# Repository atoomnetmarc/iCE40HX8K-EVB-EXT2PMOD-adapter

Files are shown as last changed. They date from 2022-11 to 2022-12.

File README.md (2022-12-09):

# iCE40HX8K-EVB-EXT to 4 PMOD port adapter.

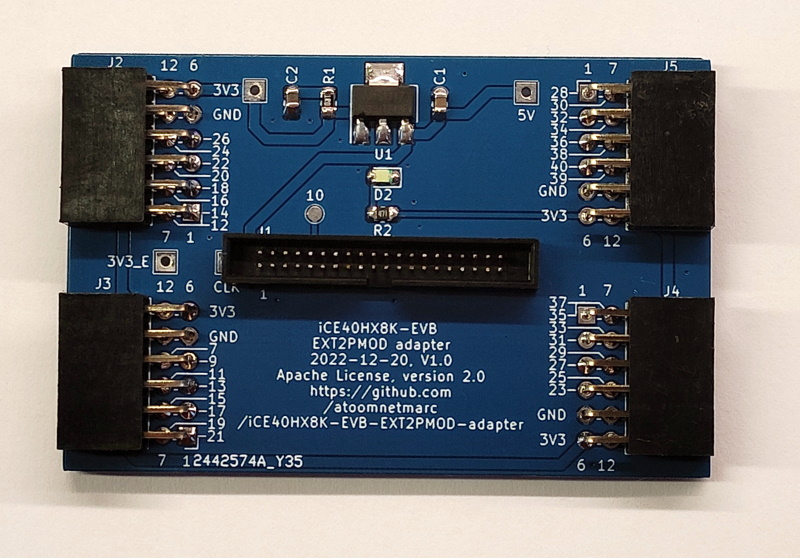
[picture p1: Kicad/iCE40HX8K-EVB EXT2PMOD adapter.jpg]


# Soldering

Solder every SMD component. Measure if 5V gets regulates to 3V3.

Solder every through-hole component. Measure for shorts between any of the signal pins on the tiny 1.27 header J1, correct if needed.

Clean the PCB.

# Pin mapping from PMOD to iCE40HX8K

Header on adapter (J2, J3, J4, J5 column) ➔ pin number on EXT connector (EXT column) ➔ FPGA pin when using EXTx (EXT1, EXT2, EXT3, EXT4 column) connector on FPGA board.

| J2 | EXT | EXT1  | EXT2  | EXT3  | EXT4  |
| -- | -- | -- | -- | -- | -- |
| 1 | 14 | A7 | K12 | D15 | M5 |
| 2 | 18 | D8 | L13 | F14 | M4 |
| 3 | 22 | F7 | L12 | D16 | N3 |
| 4 | 26 | F9 | M13 | E16 | M3 |
| 7 | 12 | C7 | M16 | F11 | R1 |
| 8 | 16 | B8 | L14 | F12 | P2 |
| 9 | 20 | B9 | N16 | G12 | P1 |
| 10 | 24 | C8 | M14 | G13 | L5 |

| J3 | EXT | EXT1  | EXT2  | EXT3  | EXT4  |
| -- | -- | -- | -- | -- | -- |
| 1 | 21 | A16 | E6 | K16 | N12 |
| 2 | 17 | E11 | A5 | J15 | M11 |
| 3 | 13 | B14 | A6 | K13 | E13 |
| 4 | 9 | B15 | C6 | J11 | F13 |
| 7 | 19 | C13 | B5 | K15 | T13 |
| 8 | 15 | C12 | D6 | K14 | D14 |
| 9 | 11 | D13 | D7 | L16 | B16 |
| 10 | 7 | C14 | B6 | M15 | C16 |

| J4 | EXT | EXT1  | EXT2  | EXT3  | EXT4  |
| -- | -- | -- | -- | -- | -- |
| 1 | 35 | B10 | B3 | H16 | L1 |
| 2 | 31 | D11 | C5 | H13 | K3 |
| 3 | 27 | E10 | D5 | J13 | J1 |
| 4 | 23 | A15 | B4 | J14 | M12 |
| 7 | 37 | B11 | D4 | H14 | K4 |
| 8 | 33 | B12 | C4 | H11 | L4 |
| 9 | 29 | C11 | A1 | J16 | K1 |
| 10 | 25 | B13 | A2 | J12 | R16 |

| J5 | EXT | EXT1  | EXT2  | EXT3  | EXT4  |
| -- | -- | -- | -- | -- | -- |
| 1 | 28 | A9 | P16 | G14 | M6 |
| 2 | 32 | E9 | P14 | G11 | L7 |
| 3 | 36 | D10 | R14 | G10 | K5 |
| 4 | 40 | A10 | D3 | H12 | L6 |
| 7 | 30 | D9 | P15 | F15 | N2 |
| 8 | 34 | C9 | R15 | F16 | M2 |
| 9 | 38 | A11 | C3 | G15 | L3 |
| 10 | 39 | C10 | E5 | G16 | M1 |



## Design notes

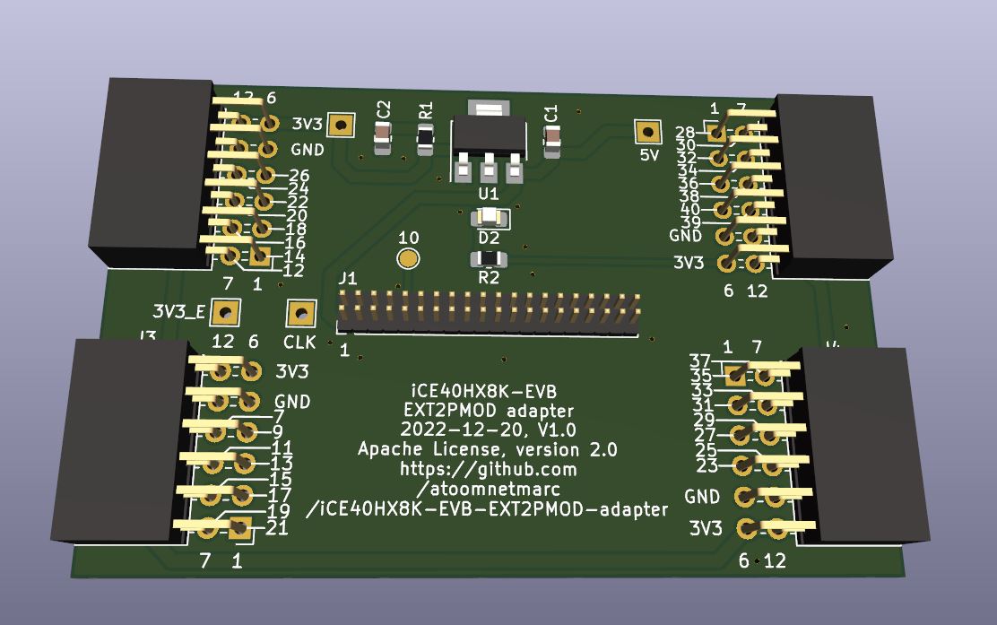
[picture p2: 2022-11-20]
Kicad/iCE40HX8K-EVB EXT2PMOD adapter-render.jpg

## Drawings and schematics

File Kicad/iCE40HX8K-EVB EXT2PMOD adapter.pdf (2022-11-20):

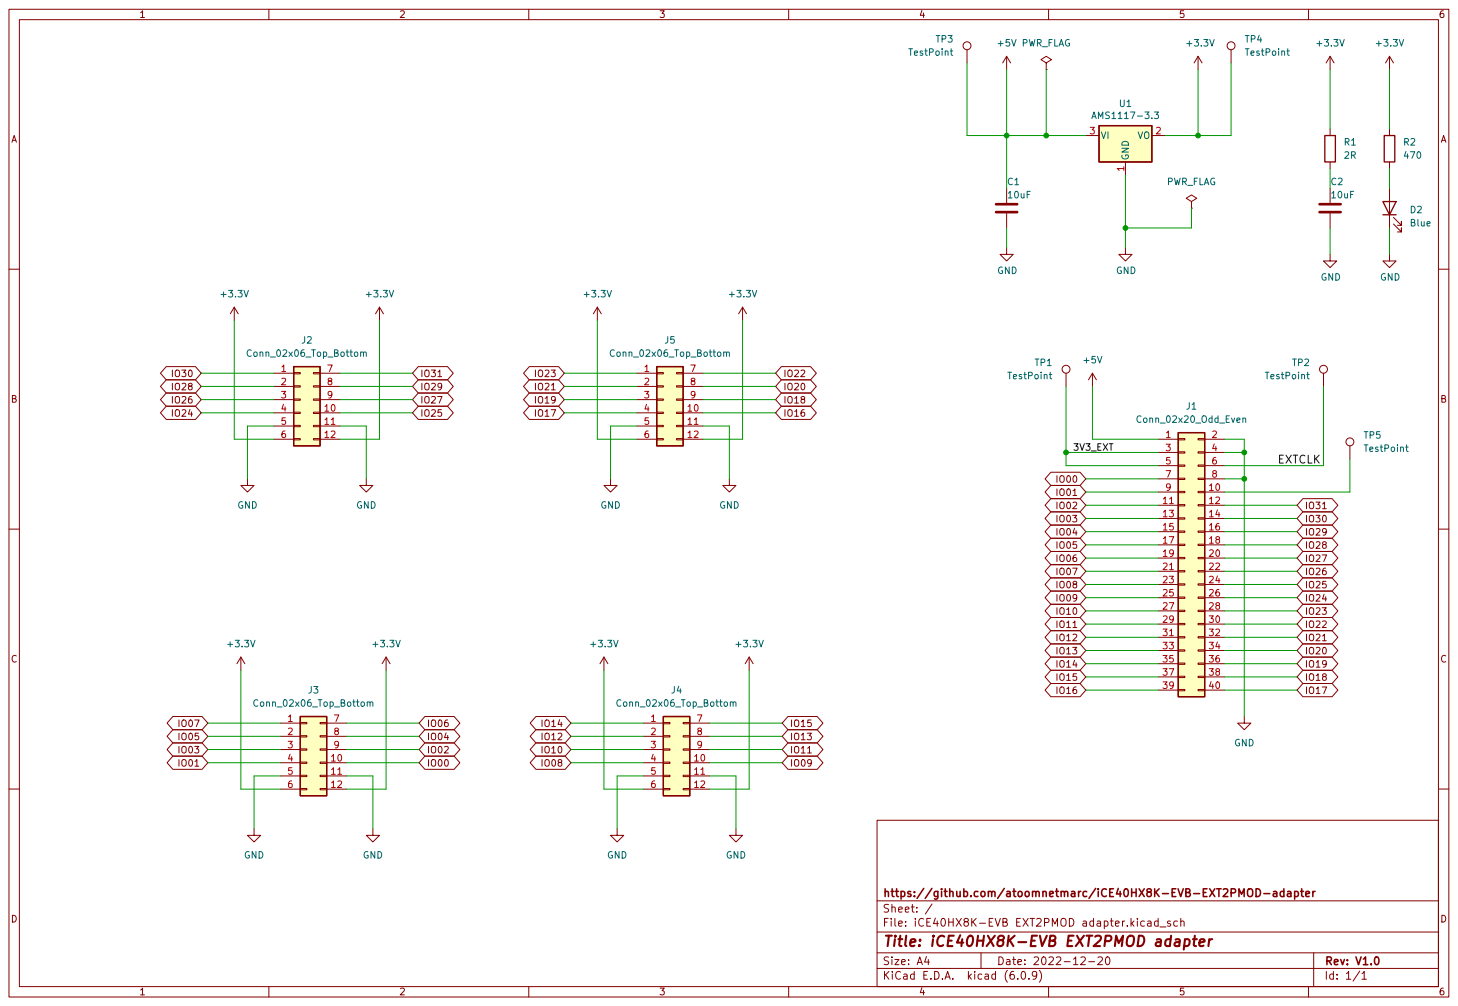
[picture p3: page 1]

File: iCE40HX8K-EVB EXT2PMOD adapter.kicad_sch Sheet: / https://github.com/atoomnetmarc/iCE40HX8K-EVB-EXT2PMOD-adapter

Id: 1/1 Title: iCE40HX8K-EVB EXT2PMOD adapter

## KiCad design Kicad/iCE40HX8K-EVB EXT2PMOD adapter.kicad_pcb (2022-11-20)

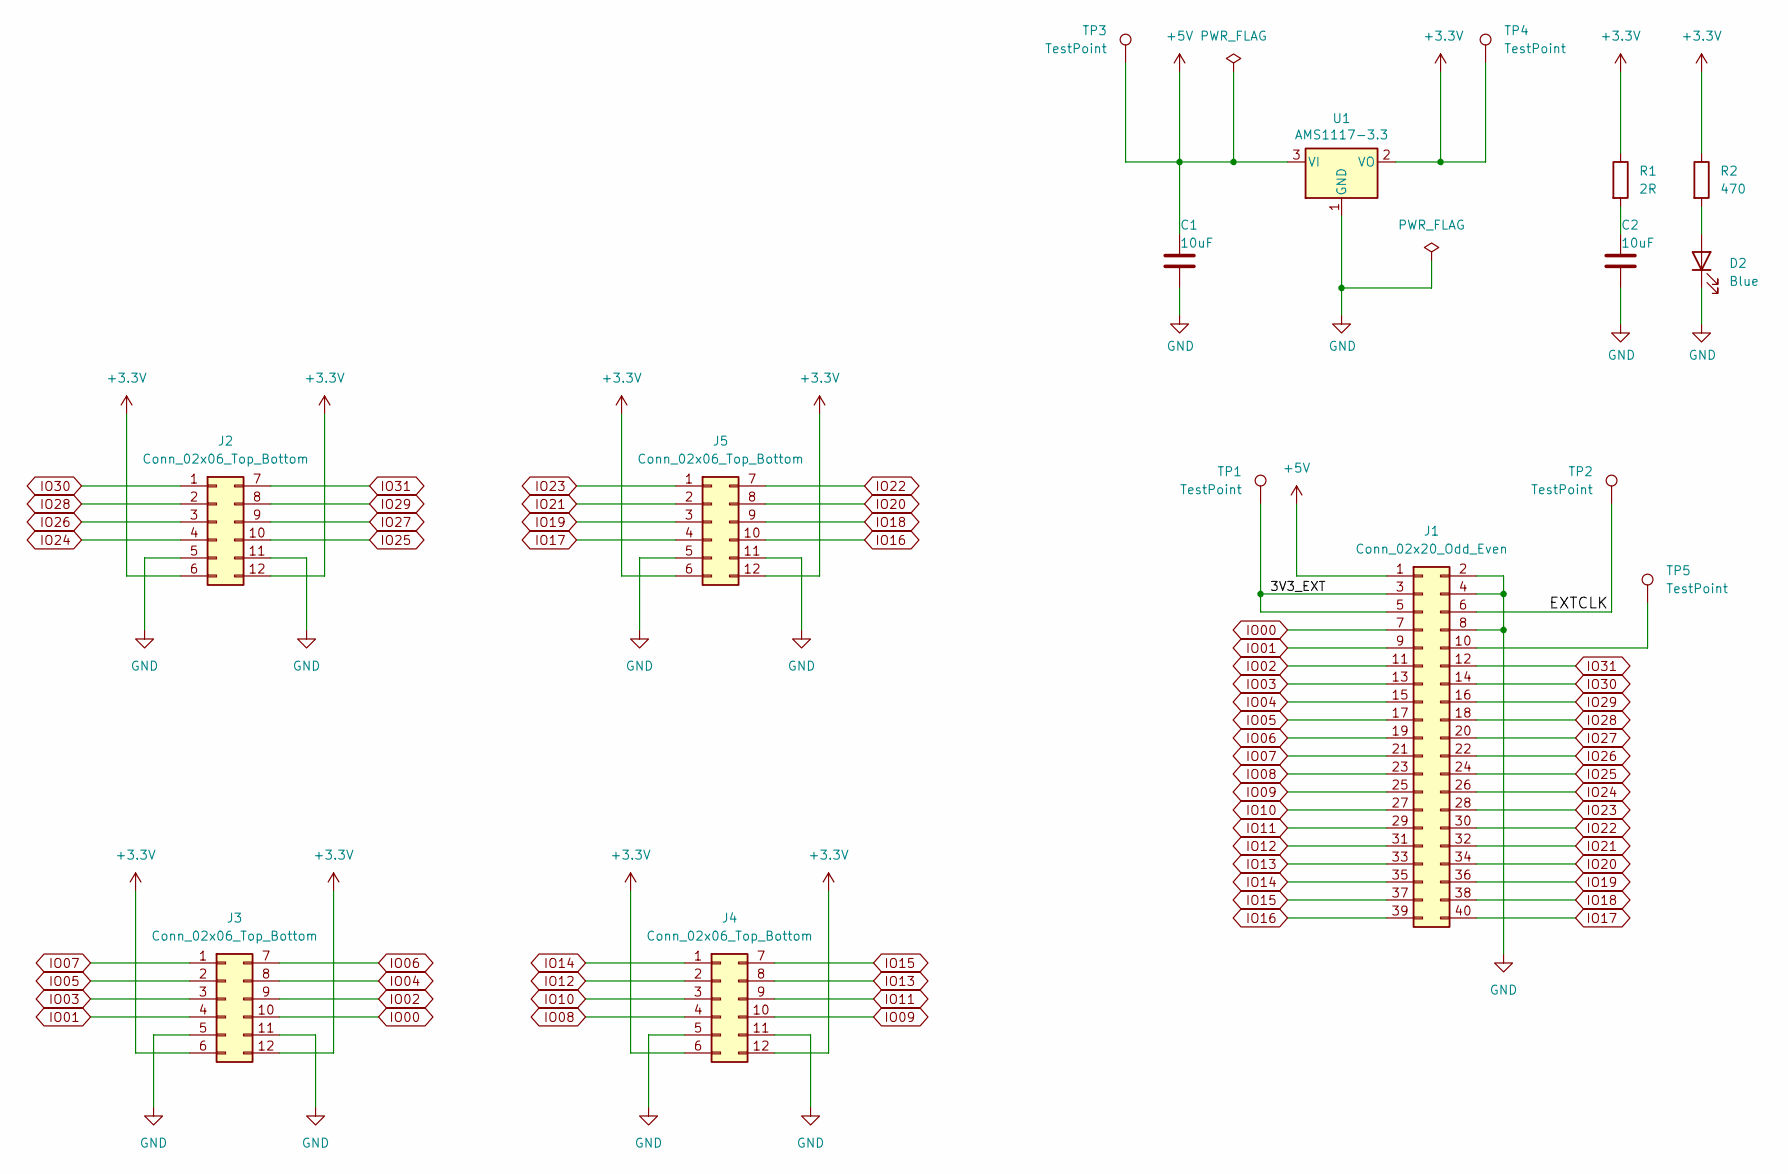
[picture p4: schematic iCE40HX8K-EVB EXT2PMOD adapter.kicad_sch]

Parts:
C1, C2: 10uF; C_0805_2012Metric_Pad1.18x1.45mm_HandSolder
D2: Blue; LED_0805_2012Metric_Pad1.15x1.40mm_HandSolder
J1: Conn_02x20_Odd_Even; PinHeader_2x20_P1.27mm_Vertical
J2, J3, J4, J5: Conn_02x06_Top_Bottom; PinSocket_2x06_P2.54mm_Horizontal_Top_Bottom
R1: 2R; R_0805_2012Metric_Pad1.20x1.40mm_HandSolder
R2: 470; R_0805_2012Metric_Pad1.20x1.40mm_HandSolder
TP1, TP2, TP3, TP4: TestPoint; TestPoint_THTPad_2.0x2.0mm_Drill1.0mm
TP5: TestPoint; TestPoint_Pad_D1.5mm
U1: AMS1117-3.3; SOT-223-3_TabPinNC

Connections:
+3.3V: J2.6, J2.12, J3.6, J3.12, J4.6, J4.12, J5.6, J5.12, R1.1, R2.1, TP4.1, U1.2 (VO)
+5V: C1.1, J1.1, TP3.1, U1.3 (VI)
/3V3_EXT: J1.3, J1.5, TP1.1
/EXTCLK: J1.6, TP2.1
GND: C1.2, C2.2, D2.1 (K), J1.2, J1.4, J1.8, J2.5, J2.11, J3.5, J3.11, J4.5, J4.11, J5.5, J5.11, U1.1 (GND)
IO00: J1.7, J3.10
IO01: J1.9, J3.4
IO02: J1.11, J3.9
IO03: J1.13, J3.3
IO04: J1.15, J3.8
IO05: J1.17, J3.2
IO06: J1.19, J3.7
IO07: J1.21, J3.1
IO08: J1.23, J4.4
IO09: J1.25, J4.10
IO10: J1.27, J4.3
IO11: J1.29, J4.9
IO12: J1.31, J4.2
IO13: J1.33, J4.8
IO14: J1.35, J4.1
IO15: J1.37, J4.7
IO16: J1.39, J5.10
IO17: J1.40, J5.4
IO18: J1.38, J5.9
IO19: J1.36, J5.3
IO20: J1.34, J5.8
IO21: J1.32, J5.2
IO22: J1.30, J5.7
IO23: J1.28, J5.1
IO24: J1.26, J2.4
IO25: J1.24, J2.10
IO26: J1.22, J2.3
IO27: J1.20, J2.9
IO28: J1.18, J2.2
IO29: J1.16, J2.8
IO30: J1.14, J2.1
IO31: J1.12, J2.7
unnamed: C2.1, R1.2
unnamed: D2.2 (A), R2.2
unnamed: J1.10, TP5.1

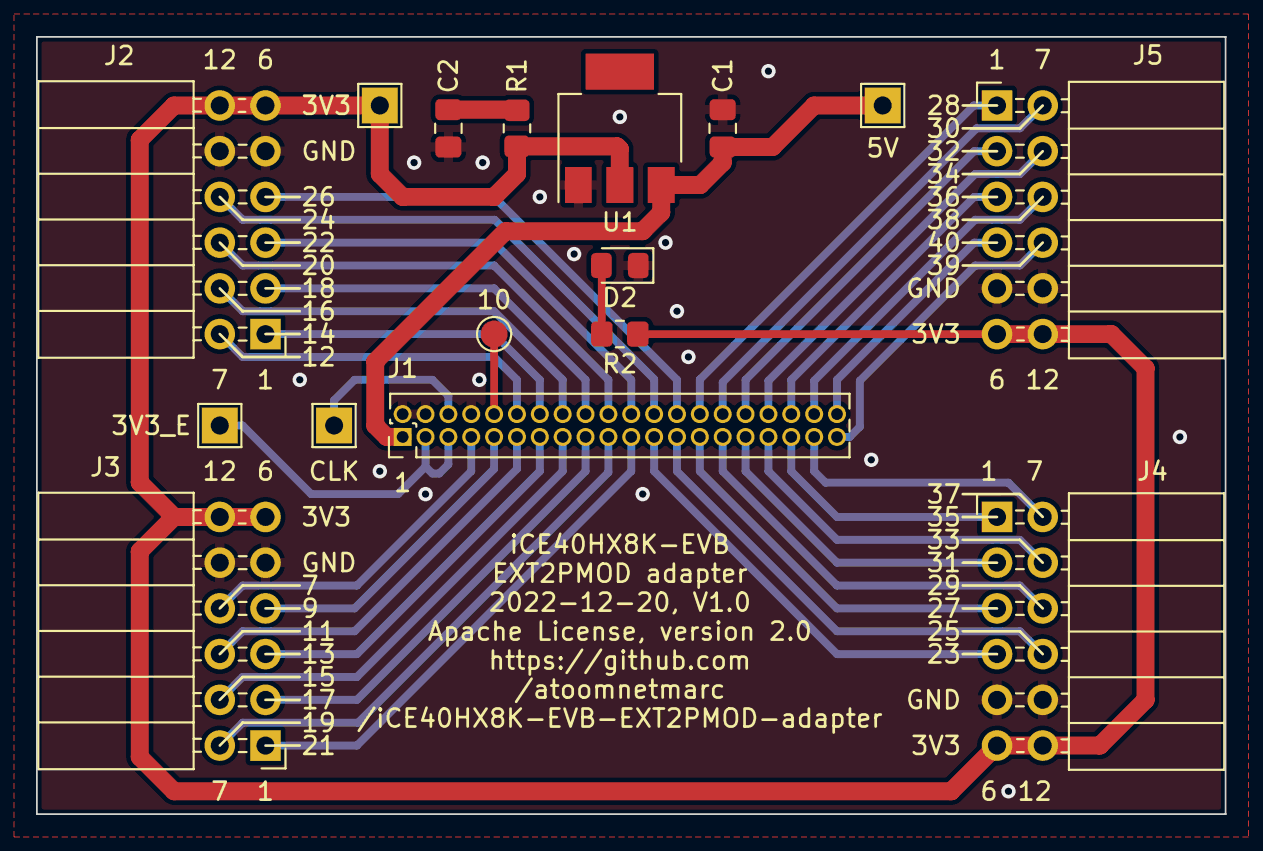
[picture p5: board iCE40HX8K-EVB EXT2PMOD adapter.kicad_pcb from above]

Board: 2 copper layers, 66.0 x 43.2 mm, 16 parts (0 on the bottom side), 40 nets.

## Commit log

2022-11-20 Initial commit.
    [iCE40HX8K-EVB EXT2PMOD adapter-B_Cu.gbl, iCE40HX8K-EVB EXT2PMOD adapter-B_Mask.gbs, iCE40HX8K-EVB EXT2PMOD adapter-B_Paste.gbp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]
2022-11-22 Start adding pin mapping tables.

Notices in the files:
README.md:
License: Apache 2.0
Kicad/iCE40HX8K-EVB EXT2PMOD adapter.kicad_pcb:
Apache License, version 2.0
